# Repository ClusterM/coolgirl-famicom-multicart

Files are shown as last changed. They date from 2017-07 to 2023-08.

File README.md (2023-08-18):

# COOLGIRL - ultimate multigame cartridge for Famicom

The goal of the project is to create a open source Famicom cartridge that will not be too expensive and can contain up to ~700 games of various mappers.

It's inspired by ultra cheap "COOLBOY" multicarts but instead of using single mapper (MMC3) "COOLGIRL" uses EPM1270T144 CPLD chip to simulate many different mappers. Both PRG and CHR data stored on a single flash memory chip. Before game starts loader loads CHR data from flash to CHR RAM and sets PRG offset, banking modes, mapper code and other settings via registers. There is lockout register bit which prevents further writes.

Full characteristics:
* PRG ROM: up to 128 MiB
* CHR RAM: up to 512 KiB
* PRG RAM: 32 KiB, non-volatile (FRAM) (optional)

## How to build
### Hardware
#### Bill of materials
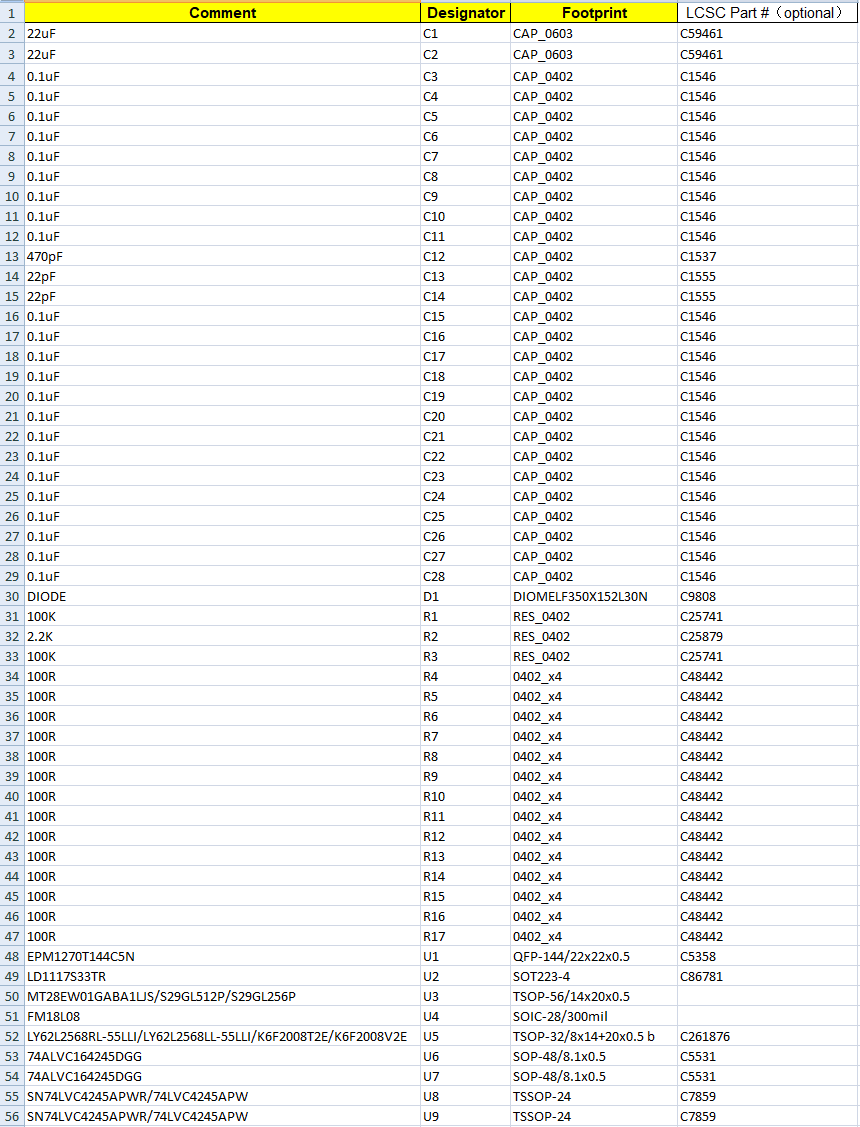
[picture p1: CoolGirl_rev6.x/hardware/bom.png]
BoM


#### Schematic
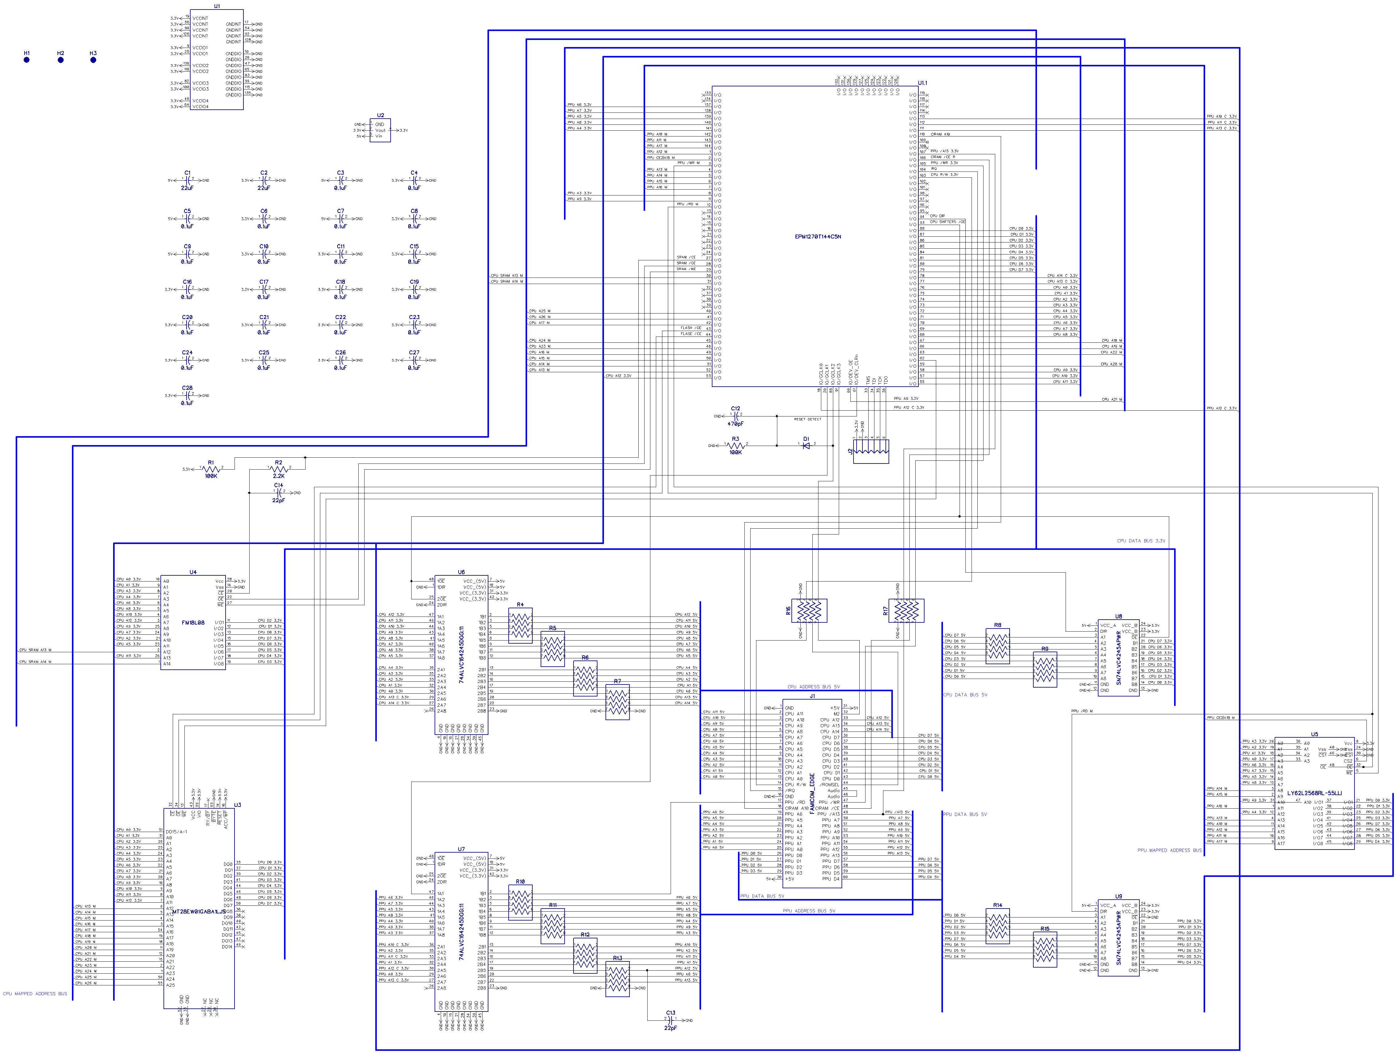
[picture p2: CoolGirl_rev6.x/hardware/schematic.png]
Schematic


The [source file](CoolGirl_rev6.x/hardware/schematic.dch) can be opened using the [DipTrace](https://diptrace.com/).

#### Board
Board designed for order on [jlcpcb.com](https://jlcpcb.com).



* Layers: 4
* PCB Thickness: 1.2mm
* Golden fingers highly recommended

The [source file](CoolGirl_rev6.x/hardware/board.dip) can be opened using the [DipTrace](https://diptrace.com/).

Generated gerberes are located in the [CoolGirl_rev6.x/hardware](CoolGirl_rev6.x/hardware) directory.

### Firmware
EPM1270T144 CPLD firmware can be compiled using the [Quartus 22.1](https://www.intel.com/content/www/us/en/collections/products/fpga/software/downloads.html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). Open [CoolGirl.qpf](CoolGirl_rev6.x/CoolGirl.qpf) to configure and compile project.

All mappers can't fit into the CPLD at once, so you need to select required mappers in (config file)[CoolGirl_config.vh], so they can fit into 1270 macrocells. Also, you can set RESET_COMBINATION parameter to specify software reset button combination, it works on original consoles and some famiclones. Default combination is 8'b11010010 (Left+Start+A+B). Set it to 0 to disable and free some macrocells.

There are JTAG pads on the cartridge board to connect programmer (USB Blaster).

### ROM preparing
You can use [COOLGIRL Multirom Builder](https://github.com/ClusterM/coolgirl-multirom-builder) to combine multiple ROMs into one with menu and loader. ROM can be written to assembled cartridge using [Famicom/NES Dumper/Writer](https://github.com/ClusterM/famicom-dumper-writer). Non-soldered flash memory chip can be written using programmer.

## Registers
Range: $5000-$5FFF

Mask: $5007

All registers are $00 on power-on and reset.

### $5xx0
```
 7  bit  0
 ---- ----
 PPPP PPPP
 |||| ||||
 ++++-++++-- PRG base offset (A29-A22)
```

### $5xx1
```
 7  bit  0
 ---- ----
 PPPP PPPP
 |||| ||||
 ++++-++++-- PRG base offset (A21-A14)
```

### $5xx2
```
 7  bit  0
 ---- ----
 AMMM MMMM
 |||| ||||
 |+++-++++-- PRG mask (A20-A14, inverted+anded with PRG address)
 +---------- CHR mask (A18, inverted+anded with CHR address)
```

### $5xx3
```
 7  bit  0
 ---- ----
 BBBC CCCC
 |||| ||||
 |||+-++++-- CHR bank A (bits 7-3)
 +++-------- PRG banking mode (see below)
```

### $5xx4
```
 7  bit  0
 ---- ----
 DDDE EEEE
 |||| ||||
 |||+-++++-- CHR mask (A17-A13, inverted+anded with CHR address)
 +++-------- CHR banking mode (see below)
```

### $5xx5
```
 7  bit  0
 ---- ----
 CDDE EEWW
 |||| ||||
 |||| ||++-- 8KiB WRAM page at $6000-$7FFF
 |+++-++---- PRG bank A (bits 5-1)
 +---------- CHR bank A (bit 8)
```

### $5xx6
```
 7  bit  0
 ---- ----
 FFFM MMMM
 |||| ||||
 |||+ ++++-- Mapper code (bits 4-0, see below)
 +++-------- Flags 2-0, functionality depends on selected mapper
```

### $5xx7
```
 7  bit  0
 ---- ----
 LMTR RSNO
 |||| |||+-- Enable WRAM (read and write) at $6000-$7FFF
 |||| ||+--- Allow writes to CHR RAM
 |||| |+---- Allow writes to flash chip
 |||+-+----- Mirroring (00=vertical, 01=horizontal, 10=1Sa, 11=1Sb)
 ||+-------- Enable four-screen mode
 |+-- ------ Mapper code (bit 5, see below)
 +---------- Lockout bit (prevent further writes to all registers)
```

## Mapper codes
```
| Code   | iNES mapper number(s) and name(s)  | Flags meaning                         | Notes                                     |
| ====== + ================================== + ===================================== + ========================================= |
| 000000 | 0 (NROM) †                         |                                       |                                           |
| ------ + ---------------------------------- + ------------------------------------- + ----------------------------------------- |
| 000001 | 2 (UxROM) †                        | 0 - enable "Fire Hawk" mirroring for  | Mapper 2 is fully compartible with mapper |
|        | 71 (Codemasters) *                 |     mapper 71 (Codemasters)           | 71 but "Fire Hawk" only uses mirroring    |
|        | 30 (UNROM-512)                     | 1 - Enable one screen mirroring       | control. UNROM-512 self-writable feature  |
|        |                                    |     select for mapper 30 (UNROM-512)  | is not supported                          |
| ------ + ---------------------------------- + ------------------------------------- + ----------------------------------------- |
| 000010 | 3 (CNROM) †                        |                                       |                                           |
| ------ + ---------------------------------- + ------------------------------------- + ----------------------------------------- |
| 000011 | 78 (Irem) *                        |                                       |                                           |
| ------ + ---------------------------------- + ------------------------------------- + ----------------------------------------- |
| 000100 | 97 (Irem's TAM-S1)                 |                                       |                                           |
| ------ + ---------------------------------- + ------------------------------------- + ----------------------------------------- |
| 000101 | 93 (Sunsoft-2) *                   |                                       |                                           |
| ------ + ---------------------------------- + ------------------------------------- + ----------------------------------------- |
| 000110 | 163 (Nanjing)                      |                                       |                                           |
| ------ + ---------------------------------- + ------------------------------------- + ----------------------------------------- |
| 000111 | 18 (Jaleco SS 88006)               |                                       |                                           |
| ------ + ---------------------------------- + ------------------------------------- + ----------------------------------------- |
| 001000 | 7 (AxROM) †                        | 0 - disable mirroring control, used   | Can be oversized to 512 KiB.              |
|        | 34 (BNROM, NINA-001) *             |     to select mapper 34 instead of 7  | iNES Mapper 034 is used to designate both |
|        |                                    |                                       | the BNROM and NINA-001 boards but only    |
|        |                                    |                                       | BNROM is supported                        |
| ------ + ---------------------------------- + ------------------------------------- + ----------------------------------------- |
| 001001 | 228 (Action 52)                    |                                       | Only Cheetahmen II is supported           |
| ------ + ---------------------------------- + ------------------------------------- + ----------------------------------------- |
| 001010 | 11 (Color Dreams) *                |                                       |                                           |
| ------ + ---------------------------------- + ------------------------------------- + ----------------------------------------- |
| 001011 | 66 (GxROM) *                       |                                       |                                           |
| ------ + ---------------------------------- + ------------------------------------- + ----------------------------------------- |
| 001100 | 87 *                               |                                       |                                           |
| ------ + ---------------------------------- + ------------------------------------- + ----------------------------------------- |
| 001101 | 90 (J.Y. Company) *                |                                       | Partial support only, can be used for     |
|        |                                    |                                       | "Aladdin" and "Super Mario World" only.   |
|        |                                    |                                       | "Super Mario World" requires to enable    |
|        |                                    |                                       | accurate IRQs and multiplier (disabled by |
|        |                                    |                                       | default)                                  |
| ------ + ---------------------------------- + ------------------------------------- + ----------------------------------------- |
| 001110 | 65 (Irem's H3001) *                |                                       |                                           |
| ------ + ---------------------------------- + ------------------------------------- + ----------------------------------------- |
| 001111 | 5 (MMC5) *                         |                                       | Experimental partically support, can be   |
|        |                                    |                                       | used for "Castlevania 3 (U)" only         |
| ------ + ---------------------------------- + ------------------------------------- + ----------------------------------------- |
| 010000 | 1 (MMC1) †                         | 0 - enable 16KiB of WRAM              |                                           |
| ------ + ---------------------------------- + ------------------------------------- + ----------------------------------------- |
| 010001 | 9 (MMC2) *                         |                                       |                                           |
|        | 10 (MMC4) *                        | 0 - 0=MMC2, 1=MMC4                    |                                           |
| ------ + ---------------------------------- + ------------------------------------- + ----------------------------------------- |
| 010010 | 70 *                               | 0 - 0=70, 1=152                       |                                           |
|        | 152 *                              |                                       |                                           |
| ------ + ---------------------------------- + ------------------------------------- + ----------------------------------------- |
| 010011 | 73 (VRC3)                          |                                       |                                           |
| ------ + ---------------------------------- + ------------------------------------- + ----------------------------------------- |
| 010100 | 4 (MMC3/MMC6) †                    | 0 - use mapper 118 (TxROM)            | Can be oversized up to 2 MiB              |
|        | 118 (TxROM) *                      | 1 - use mapper 189                    |                                           |
|        | 189 *                              | 2 - use mapper 206                    |                                           |
|        | 206 (Namco, Tengen, others)        |                                       |                                           |
| ------ + ---------------------------------- + ------------------------------------- + ----------------------------------------- |
| 010101 | 112                                |                                       |                                           |
| ------ + ---------------------------------- + ------------------------------------- + ----------------------------------------- |
| 010110 | 33 (Taito) *                       | 0 - 0=33, 1=48                        |                                           |
|        | 48 (Taito) *                       |                                       |                                           |
| ------ + ---------------------------------- + ------------------------------------- + ----------------------------------------- |
| 010111 | 42 (FDS conversions) *             |                                       | Interrupts disabled by default            |
| ------ + ---------------------------------- + ------------------------------------- + ----------------------------------------- |
| 011000 | 21 (VRC2/VRC4) *                   | 2,0 - A0 and A1 lines configuration:  |                                           |
|        | 22 (VRC2/VRC4) *                   |     0,0 - like mapper 21              |                                           |
|        | 23 (VRC2/VRC4) *                   |     0,1 - like mapper 22              |                                           |
|        | 25 (VRC2/VRC4) *                   |     1,0 - like mapper 23              |                                           |
|        |                                    |     1,1 - like mapper 25              |                                           |
|        |                                    | 1 - divide CHR bank select by two     |                                           |
|        |                                    |     (VRC2a, mapper 22)                |                                           |
| ------ + ---------------------------------- + ------------------------------------- + ----------------------------------------- |
| 011001 | 69 (Sunsoft FME-7) *               |                                       |                                           |
| ------ + ---------------------------------- + ------------------------------------- + ----------------------------------------- |
| 011010 | 32 (IREM G-101) *                  |                                       |                                           |
| ------ + ---------------------------------- + ------------------------------------- + ----------------------------------------- |
| 011011 | 79 (NINA-03/06)                    |                                       |                                           |
|        | 146 (Sachen 3015)                  |                                       |                                           |
| ------ + ---------------------------------- + ------------------------------------- + ----------------------------------------- |
| 011100 | 133 (Sachen)                       |                                       |                                           |
| ------ + ---------------------------------- + ------------------------------------- + ----------------------------------------- |
| 011101 | 36 (TXC's PCB 01-22000-400)        |                                       |                                           |
| ------ + ---------------------------------- + ------------------------------------- + ----------------------------------------- |
| 011110 | Reserved                           |                                       |                                           |
| ------ + ---------------------------------- + ------------------------------------- + ----------------------------------------- |
| 011111 | 184 (Sunsoft-1)                    |                                       |                                           |
| ------ + ---------------------------------- + ------------------------------------- + ----------------------------------------- |
| 100000 | 38                                 |                                       |                                           |
| ------ + ---------------------------------- + ------------------------------------- + ----------------------------------------- |
| 100001 | Reserved                           |                                       |                                           |
| ------ + ---------------------------------- + ------------------------------------- + ----------------------------------------- |
| 100010 | 75 (VRC1)                          |                                       |                                           |
| ------ + ---------------------------------- + ------------------------------------- + ----------------------------------------- |
| 100011 | 83                                 | 0 - DIP switch 0                      | Partial support, submapper 1 requires     |
|        |                                    | 1 - DIP switch 1                      | 512 KiB of CHR RAM                        |
|        |                                    | 2 - use submapper 1                   |                                           |
| ------ + ---------------------------------- + ------------------------------------- + ----------------------------------------- |
| 100100 | 67 (Sunsoft-3)                     |                                       |                                           |
| ------ + ---------------------------------- + ------------------------------------- + ----------------------------------------- |
| 100101 | 89 (Sunsoft-2 on Sunsoft-3 PCB)    |                                       |                                           |
| ------ + ---------------------------------- + ------------------------------------- + ----------------------------------------- |
| ...... | Reserved                           |                                       |                                           |

† - very popular mappers, can't be disabled in config
* - enabled by default in config
```

## PRG banking modes
```
| Code | $8000 | $A000 | $E000 | $C000 | Notes                                    |
| ==== + ===== + ===== + ===== + ===== + ======================================== |
| 000  |       A       |       C       | UxROM, MMC4, MMC1 mode #3, etc.          |
| ---- + ------------- + ------------- + ---------------------------------------- |
| 001  |       C       |       A       | Mapper 97 (TAM-S1)                       |
| ---- + ------------- + ------------- + ---------------------------------------- |
| 010  |           Reserved            |                                          |
| ---- + ----------------------------- + ---------------------------------------- |
| 011  |           Reserved            |                                          |
| ---- + ----- + ----- + ----- + ----- + ---------------------------------------- |
| 100  |   A   |   B   |   C   |   D   | Universal, used by MMC3 mode 0, etc.     |
| ---- + ----- + ----- + ----- + ----- + ---------------------------------------- |
| 101  |   C   |   B   |   A   |   D   | MMC3 mode 1                              |
| ---- + ----- + ----- + ----- + ----- + ---------------------------------------- |
| 110  |               B               | Mapper 163                               |
| ---- + ----------------------------- + ---------------------------------------- |
| 111  |               A               | AxROM, MMC1 modes 0/1, Color Dreams      |
```
Power-on/reset state: A=0, B=~2, C=~1, D=~0

## CHR banking modes
```
| Code | $0000 | $0400 | $0800 | $0C00 | $1000 | $1400 | $1800 | $1C00 | Notes                                    |
| ==== + ===== + ===== + ===== + ===== + ===== + ===== + ===== + ===== + ======================================== |
| 000  |                               A                               | Used by many simple mappers              |
| ---- + ------------------------------------------------------------- + ---------------------------------------- |
| 001  |                          Spetial mode                         | Used by mapper 163                       |
| ---- + ----- + ----- + ----- + ----- + ----- + ----- + ----- + ----- + ---------------------------------------- |
| 010  |       A       |       C       |   E   |   F   |   G   |   H   | Used by MMC3 mode 0                      |
| ---- + ----- + ----- + ----- + ----- + ----- + ----- + ----- + ----- + ---------------------------------------- |
| 011  |   E   |   F   |   G   |   H   |       A       |       C       | Used by MMC3 mode 1                      |
| ---- + ----- + ----- + ----- + ----- + ------------- + ------------- + ---------------------------------------- |
| 100  |               A               |               E               | Used by MMC1                             |
| ---- + ----------------------------- + ------------- + ------------- + ---------------------------------------- |
| 101  |              A/B              |              E/F              | MMC2/MMC4, switched by tiles $FD or $FE  |
| ---- + ------- ----- + ------------- + ------------- + ------------- + ---------------------------------------- |
| 110  |       A       |       C       |       E       |       G       | Used by many complicated mappers         |
| ---- + ----- + ----- + ----- + ----- + ----- + ----- + ----- + ----- + ---------------------------------------- |
| 111  |   A   |   B   |   C   |   D   |   E   |  F    |   G   |   H   | Used by very complicated mappers         |
```
Power-on/reset state: A=0, B=1, C=2, D=3, E=4, F=5, G=6, H=7

## Donate
* PayPal: cluster@cluster.wtf
* [Donation Alerts](https://www.donationalerts.com/r/clustermeerkat)
* [Boosty](https://boosty.to/cluster)

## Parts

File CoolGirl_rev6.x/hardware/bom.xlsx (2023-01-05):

Comment | Designator | Footprint | LCSC Part #（optional）
22uF | C1 | CAP_0603 | C59461
22uF | C2 | CAP_0603 | C59461
0.1uF | C3 | CAP_0402 | C1546
0.1uF | C4 | CAP_0402 | C1546
0.1uF | C5 | CAP_0402 | C1546
0.1uF | C6 | CAP_0402 | C1546
0.1uF | C7 | CAP_0402 | C1546
0.1uF | C8 | CAP_0402 | C1546
0.1uF | C9 | CAP_0402 | C1546
0.1uF | C10 | CAP_0402 | C1546
0.1uF | C11 | CAP_0402 | C1546
470pF | C12 | CAP_0402 | C1537
22pF | C13 | CAP_0402 | C1555
22pF | C14 | CAP_0402 | C1555
0.1uF | C15 | CAP_0402 | C1546
0.1uF | C16 | CAP_0402 | C1546
0.1uF | C17 | CAP_0402 | C1546
0.1uF | C18 | CAP_0402 | C1546
0.1uF | C19 | CAP_0402 | C1546
0.1uF | C20 | CAP_0402 | C1546
0.1uF | C21 | CAP_0402 | C1546
0.1uF | C22 | CAP_0402 | C1546
0.1uF | C23 | CAP_0402 | C1546
0.1uF | C24 | CAP_0402 | C1546
0.1uF | C25 | CAP_0402 | C1546
0.1uF | C26 | CAP_0402 | C1546
0.1uF | C27 | CAP_0402 | C1546
0.1uF | C28 | CAP_0402 | C1546
DIODE | D1 | DIOMELF350X152L30N | C9808
100K | R1 | RES_0402 | C25741
2.2K | R2 | RES_0402 | C25879
100K | R3 | RES_0402 | C25741
100R | R4 | 0402_x4 | C48442
100R | R5 | 0402_x4 | C48442
100R | R6 | 0402_x4 | C48442
100R | R7 | 0402_x4 | C48442
100R | R8 | 0402_x4 | C48442
100R | R9 | 0402_x4 | C48442
100R | R10 | 0402_x4 | C48442
100R | R11 | 0402_x4 | C48442
100R | R12 | 0402_x4 | C48442
100R | R13 | 0402_x4 | C48442
100R | R14 | 0402_x4 | C48442
100R | R15 | 0402_x4 | C48442
100R | R16 | 0402_x4 | C48442
100R | R17 | 0402_x4 | C48442
EPM1270T144C5N | U1 | QFP-144/22x22x0.5 | C5358
LD1117S33TR | U2 | SOT223-4 | C86781
MT28EW01GABA1LJS/S29GL512P/S29GL256P | U3 | TSOP-56/14x20x0.5
FM18L08 | U4 | SOIC-28/300mil
LY62L2568RL-55LLI/LY62L2568LL-55LLI/K6F2008T2E/K6F2008V2E | U5 | TSOP-32/8x14+20x0.5 b | C261876
74ALVC164245DGG | U6 | SOP-48/8.1x0.5 | C5531
74ALVC164245DGG | U7 | SOP-48/8.1x0.5 | C5531
SN74LVC4245APWR/74LVC4245APW | U8 | TSSOP-24 | C7859
SN74LVC4245APWR/74LVC4245APW | U9 | TSSOP-24 | C7859

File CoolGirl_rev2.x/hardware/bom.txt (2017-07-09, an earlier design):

U1: EPM1270T144
U2: LD1117S33
U3: S29GL01GP, S29GL512P, S29GL256P, S29GL512N or S29GL256N (depending on capacity) in TSOP package
U4: UT62256CSC
U5: K6F2008T2E or K6F2008V2E
U6: SN74ALVC164245DGGR
U7: SN74ALVC164245DGGR
U8: SN74LVC8T245PWR
U9: SN74LVC8T245PWR
C1: 0.1uF
C2: 4.7uF
C3: 0.1uF
C4: 0.1uF
C5: 0.1uF
C6: 0.1uF
C7: 0.1uF
C8: 0.1uF
C9: 0.1uF
C10: 0.1uF
C11: 470pF
C12: 22pF
C13: 22pF
D1: DIODE
D2: DIODE
D3: DIODE
R1: 100K
R2: 2.2K
R3: 100K
R4: 2.2K
R5: 100
R6: 100
R7: 100
R8: 100
R9: 100
R10: 200
R11: 200
B1: BS-5 CR2032 or just CR2032

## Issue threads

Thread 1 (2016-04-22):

Замечания по проекту ПЛИС

ivantaran, 2016-04-22:
Есть предложение, всё-таки, воспользоваться TimeQuest'ом и описать констрейны в проекте, например, тактовые цепи:
- m2
- ppu_addr_in[12]
Также имеется куча "Unconstrained Paths" - над этим не плохо бы подумать.
Констрейны - залог стабильной работы проекта.

Ну и по Verilog:
- напрашивается разбиение на модули
- запись в регистры принято писать через оператор неблокирующего присваивания "<=", это не важно для синтеза, но для симуляции весьма желательно:

line 685:             if (ppu_addr_in[13:3] == 11'b00111111011) ppu_latch0 = 0;    // не хорошо

line 685:             if (ppu_addr_in[13:3] == 11'b00111111011) ppu_latch0 <= 0;    // ок

- очень громоздкие конструкции:

line 151:         	   wire [17:10] ppu_addr_mapped = chr_mode[2] ? (...

почему не воспользоваться асинхронным case'ом?

darleiv, 2020-07-18:
@

Closed 2016-07-17.

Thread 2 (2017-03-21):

[Enhancement] Add Readme and Help

black-pudding, 2017-03-21:
Could it be possible to add more explanation of what this project is about?
How and where this ultimate cartridge can be made or can be bought?

ClusterM, 2017-07-08:
Yes, it's planned. I just can't find free time to do it.

38293312, 2020-05-19:
The following message appears during compilation：
Warning (10240): Verilog HDL Always Construct warning at mappers.vh(1026): inferring latch(es) for variable "irq_scanline_ready", which holds its previous value in one or more paths through the always construct
Warning (10240): Verilog HDL Always Construct warning at mappers.vh(1026): inferring latch(es) for variable "irq_scanline_out", which holds its previous value in one or more paths through the always construct
Warning (21074): Design contains 3 input pin(s) that do not drive logic
	Warning (15610): No output dependent on input pin "ppu_addr_in[0]"
	Warning (15610): No output dependent on input pin "ppu_addr_in[1]"
	Warning (15610): No output dependent on input pin "ppu_addr_in[2]"
Warning (335093): TimeQuest Timing Analyzer is analyzing 2 combinational loops as latches.
Critical Warning (332012): Synopsys Design Constraints File file not found: 'CoolGirl.sdc'. A Synopsys Design Constraints File is required by the TimeQuest Timing Analyzer to get proper timing constraints. Without it, the Compiler will not properly optimize the design.
Warning (169174): The Reserve All Unused Pins setting has not been specified, and will default to 'As output driving ground'.
Warning (335093): TimeQuest Timing Analyzer is analyzing 2 combinational loops as latches.
Critical Warning (332012): Synopsys Design Constraints File file not found: 'CoolGirl.sdc'. A Synopsys Design Constraints File is required by the TimeQuest Timing Analyzer to get proper timing constraints. Without it, the Compiler will not properly optimize the design.
Critical Warning (332148): Timing requirements not met

ClusterM, 2020-07-25:
Soon.

Closed 2020-09-14.

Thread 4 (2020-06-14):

HELP MR CLUSTER QUARTUS II ERROR in EPM1270T144

darleiv, 2020-06-14:
Error: Peak virtual memory: 235 megabytes

when I use the EPM1270T144 in the quartus it returns this error Error: Peak virtual memory: 235 megabytes, what can it be? because if I select a more powerful one, but it doesn't match your scheme

darleiv, 2020-06-14:
https://ibb.co/SXdg1Lx

darleiv, 2020-07-10:
когда я использую EPM1270T144 в квартусе, он возвращает эту ошибку Ошибка: Пиковая виртуальная память: 235 мегабайт, что это может быть? потому что, если я выберу более мощный, но он не соответствует вашей схеме
https://ibb.co/SXdg1Lx epm2210 компилирует это не

ClusterM, 2020-07-25:
I have no idea :( Which version of Quartus are you using?

darleiv, 2020-07-26:
hello cluster; Should be it. I noticed that you used Quartus 17 Lite. I use 8.1 kkk

привет кластер; Должно быть так. Я заметил, что вы использовали Quartus 17 Lite. Я использую 8.1 ккк

Я опустил 17 на лоб

Closed 2020-09-11.

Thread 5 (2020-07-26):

наконечник

darleiv, 2020-07-26:
кластер, потому что вы не можете поместить слои STOP в слот для карт, как этот вид
https://ibb.co/9swNBWJ
https://ibb.co/xLr65g1
https://ibb.co/3WxLNFD

ClusterM, 2020-09-10:
Please use English language.

Closed 2020-09-11.

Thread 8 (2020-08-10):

millimeter of the plate important question

darleiv, 2020-08-10:
large enema your plate is 6 mm at this angle. and I measured some and they measure 7mm made by farid .. nes dev. which is the ideal 6mm or 7mm? note in the photo where I mean
https://ibb.co/s9FDVRD
https://ibb.co/zsGZ9Ct
https://ibb.co/J3mV4vs
https://ibb.co/RC80XmF
https://ibb.co/8j9QXxT

ClusterM, 2020-09-10:
I think that it's not important because the circuit board is retained by the pass.

Closed 2020-09-11.

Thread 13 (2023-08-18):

Captain Saver (J).nes (Mapper 33) Image not working properly

flamecyclone, 2023-08-18:
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

Normal should be as follows
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
[games.zip](https://github.com/ClusterM/coolgirl-famicom-multicart/files/12377391/games.zip)

ClusterM, 2023-09-15:
Captain Saver is mapper #48 only. Mapper #33 is assigned by mistake.

ClusterM, 2023-09-15:
Mapper number should be automatically fixed based on info from `nes-fixes.json`. It will not work if `nes-fixes.json` is missed or ROM is hacked.

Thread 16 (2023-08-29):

Chips replacement

Domas59, 2023-08-29:
Hi
Is it possible to replace the epm1270gt144c4 with the epm1270t144c5n?

ClusterM, 2023-09-15:
Hi! Unfortunately, no. Letter "G" means that it's low-power, e.g. must be powered from 1.8V.

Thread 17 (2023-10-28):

flash write timeout.

agentxxxxxx, 2023-10-28:
I pickup S29GL512P for the flash of the cartdrige. client can't flash from sector #1.
I changed S29GL256P from another supplier. there is the same problem.

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

I dumped part of the uncompleted writing data and found the it cant write data from $25000. it seems it's not the address line problem.

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

ClusterM, 2024-08-13:
Usually it means just bad soldeing.

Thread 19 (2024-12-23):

timespan overflowed？

hualazimo7, 2024-12-23:
I used S29gl01G, error happened when writing at sector 500-600.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
I have tested two chips on different boards, error still exsited

ClusterM, 2024-12-25:
Weird error. Which client/dumper versions are you using? Are you really writing cartridge for **three hours**?

hualazimo7, 2024-12-25:
> Weird error. Which client/dumper versions are you using? Are you really writing cartridge for **three hours**?

yeah, I have built a latest stm32&cpld dumper, while it is at my another house so I just use the slower ATMEGA dumper to write a 128MB rom.
The error happens.
Maybe the client has a limit for running duration？

ClusterM, 2024-12-29:
Did you tried again? Looks like a bad flash memory. You can specify a bad sector number.
S29GL01G is not recommended at all.

hualazimo7, 2024-12-29:
I got my stm32+cpld dumper yesterday, everything is ok with the same memory flash S29GL010g. It seems like an issue with the client.

hualazimo7, 2024-12-29:
> Did you tried again? Looks like a bad flash memory. You can specify a bad sector number.
> S29GL01G is not recommended at all.

I got my stm32+cpld dumper yesterday, everything is ok with the same memory flash S29GL010g. It seems like an issue with the client.

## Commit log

2016-01-22 Taito interrupts are optional now
2016-01-29 Board files
    [BoardOutline.gbr, Bottom.gbr, BottomMask.gbr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]
2016-05-31 New generation!
    [BoardOutline.gbr, Bottom.gbr, BottomMask.gbr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]
2016-06-12 Some board fixes
    [Bottom.gbr, BottomMask.gbr, BottomSilk.gbr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]
2016-06-12 Schematics and component list
2016-07-12 Minor board fix
    [Top.gbr]
2017-07-09 Mapper #42, many fixes
    [BoardOutline.gbr, Bottom.gbr, BottomMask.gbr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]
2020-07-25 Version 3.0
    [1 - Top.gbr, 2 - Inner 1.gbr, 3 - Inner 2.gbr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]
2020-07-27 Better power routing
    [1 - Top.gbr, 2 - Inner 1.gbr, 3 - Inner 2.gbr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]
2020-07-29 Rev. 4.0
    [1 - Top.gbr, 2 - Inner 1.gbr, 3 - Inner 2.gbr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]
2020-07-29 Correct BOM and pickplace for jlcpcb.com
    [bom.csv, bom.xlsx, pickplace.csv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]
2020-09-10 5.1 (based on branch 3.x)
    [1 - Top.gbr, 2 - Inner 1.gbr, 3 - Inner 2.gbr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]
2020-09-11 Pin planner fix
2020-09-14 Interrupts stuff and refactoring
2020-09-14 Fixed another error in pin planner
2020-09-15 Moving to subdirectory
    [1 - Top.gbr, 2 - Inner 1.gbr, 3 - Inner 2.gbr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]
2020-09-22 New revision: 6.x, minor pinout changes, PPU A12 connected to clock input now.
    [1 - Top.gbr, 2 - Inner 1.gbr, 3 - Inner 2.gbr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]
2020-09-22 Minor board outline changes
    [1 - Top.gbr, 2 - Inner 1.gbr, 3 - Inner 2.gbr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]
2020-11-11 Changed PCB size for cotoff
    [1 - Top.gbr, 2 - Inner 1.gbr, 3 - Inner 2.gbr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]
2020-12-09 Soldering mask fix
    [2 - Inner 1.gbr, 3 - Inner 2.gbr, 4 - Bottom.gbr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]
2020-12-11 Minor mask changes (opened edge)
    [1 - Top.gbr, 2 - Inner 1.gbr, 3 - Inner 2.gbr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]
2020-12-19 Enable mapper 70 and AC-08 by default
    [bom.xlsx]
2020-12-19 Changed flash to MT28EW01GABA1LJS
    [bom.xlsx]
2021-01-16 LY62L2568LL-55LLI replaced with LY62L2568RL-55LLI, center hole moved a bit, revision 6.3
    [1 - Top.gbr, 2 - Inner 1.gbr, 3 - Inner 2.gbr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]
2021-01-16 LD1117-3.3 replaced with LD1117S33TR
    [bom.xlsx]
2021-01-22 Connected WP# to VDD, fixes
    [1 - Top.gbr, 4 - Bottom.gbr, TopSilk.gbr]
2021-02-18 Updated BoM
    [bom.xlsx]
2021-04-25 VRC4 interrupts fix
2023-01-05 Files moved, readme upadted
    [1 - Top.gbr, 2 - Inner 1.gbr, 3 - Inner 2.gbr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]
2023-01-05 Comments, BoM
